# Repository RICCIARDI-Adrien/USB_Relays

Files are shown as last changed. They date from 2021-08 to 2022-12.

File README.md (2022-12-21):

# USB relays

Control separately 16 signal relays through a PC by using a standard USB connection and a simple text-based serial protocol.  
Each relay can switch up to 3A at 24VDC (warning : this board is not designed for AC current).  
There is no need for a separate power supply to power the board, it is designed to be fully powered by the USB connection (that's why small relays are used).

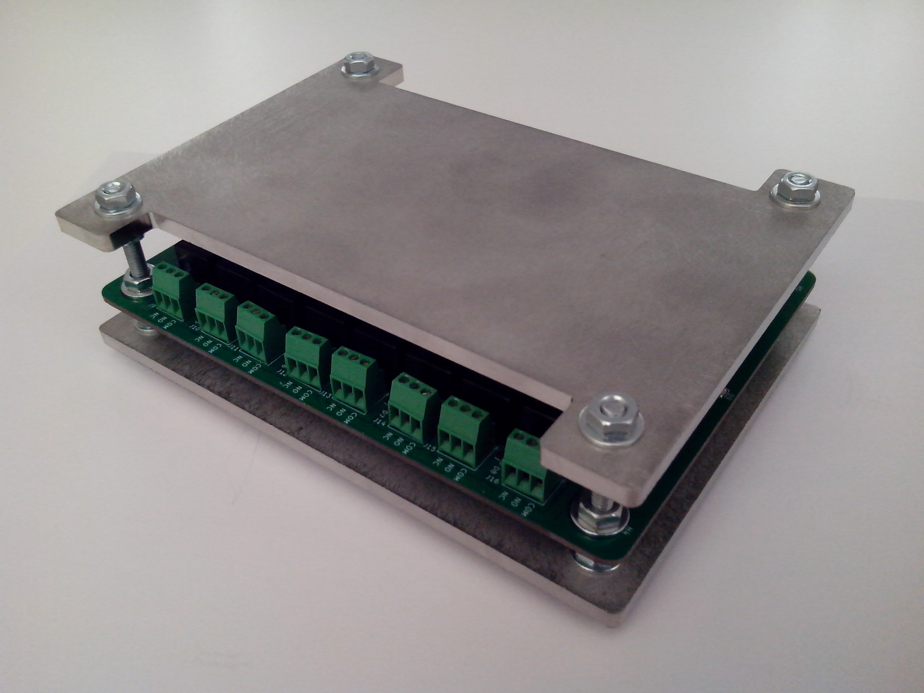
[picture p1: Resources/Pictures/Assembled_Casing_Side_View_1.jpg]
Assembled casing side view

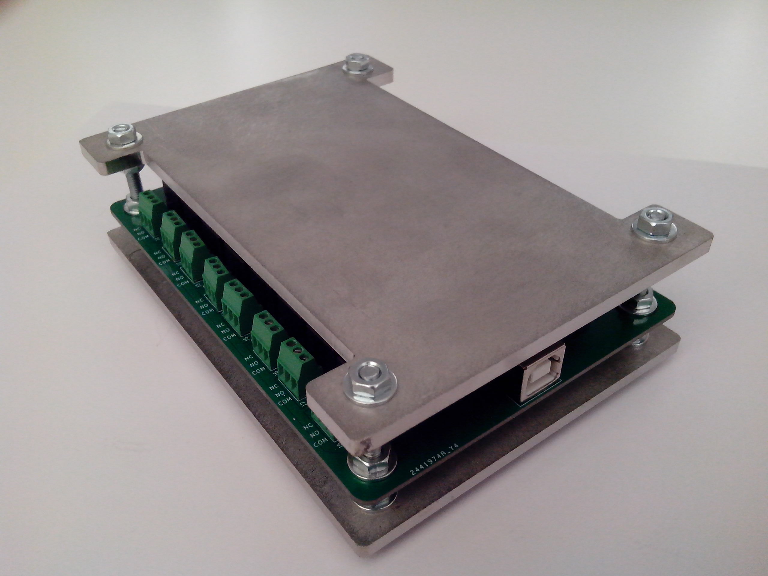
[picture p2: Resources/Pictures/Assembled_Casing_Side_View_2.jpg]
Assembled casing side view


## Communication protocol

* The board provides an USB serial port with the following settings : **115200 bits/s, no parity, 1 stop bit**.
* All commands are ASCII-only to allow to easily use the board with a simple serial port terminal like `Putty`, `minicom`, `picocom`, etc. If you plan to send commands manually, enable local echo and send CRLF when pressing enter key (see below). Here is an example picocom command invocation : `picocom --echo --omap crcrlf -b 115200 /dev/ttyUSB0`.
* All commands start with the character `#`. This way, if you mess up and write the commands into an UNIX terminal, they will be interpreted as comments.
* All commands end with CRLF characters (`\r\n`), so you only have to press `enter` key to send the command to the board.
* All commands sent to the board return an answer, the board will ignore all other commands while it is processing the current one. This allows to throttle a fast PC sending too much commands at a time, it must wait for each command answer before sending the next one.
* If you don't know the board state (for instance, the PC rebooted while it was sending a command and the board has received an incomplete command and is stuck waiting for the remaining part of the command), send the `!` character at any time. The board will immediately clear its reception buffer.

## Commands list

Use the `#H<CR><LF>` command to display the following list of commands :
```
Commands :
  - Get a relay state : #Gxx
    'xx' is the relay ID, from 1 to 16.
  - Display this help : #H
  - Set led state : #Lv
    'v' is the led state value (0 to turn off, 1 to turn on, 2 to make it blink).
  - Set relay state : #Sxxv
    'xx' is the relay ID, from 1 to 16.
    'v' is the relay state value (0 to clear, 1 to set).
  - Get firmware version : #V
```

## Photo gallery

### Casing plates

Plates are made of 4mm-thick 304 stainless steel.
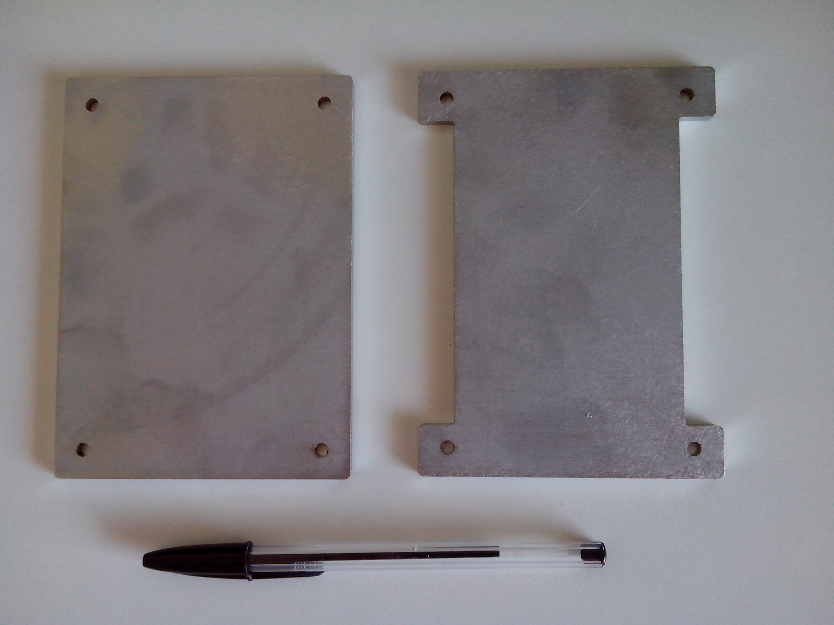
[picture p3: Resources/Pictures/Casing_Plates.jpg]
Casing plates


### PCB

PCB top :
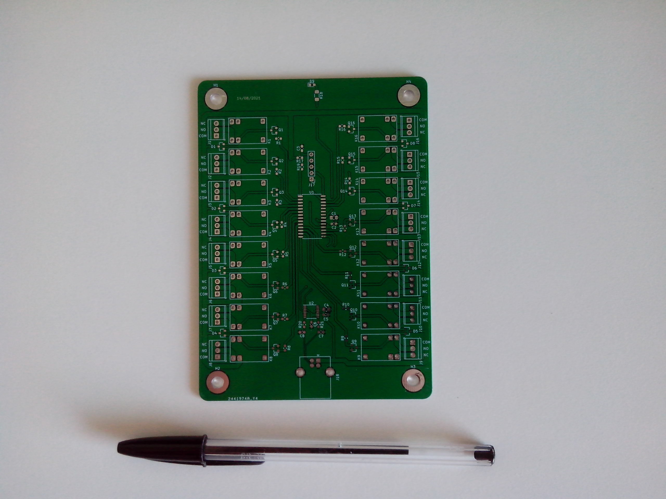
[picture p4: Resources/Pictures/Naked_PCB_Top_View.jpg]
PCB top view


PCB bottom :
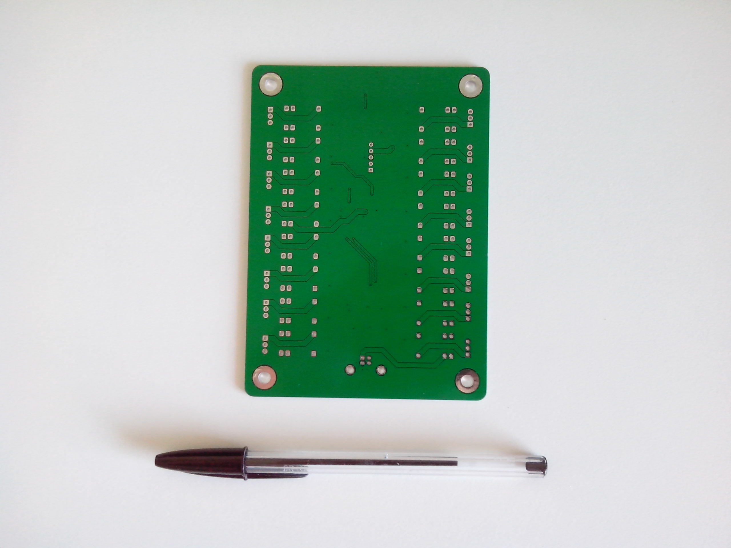
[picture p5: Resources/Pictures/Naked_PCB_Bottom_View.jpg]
PCB bottom view


### Assembled PCB

Assembled PCB top :
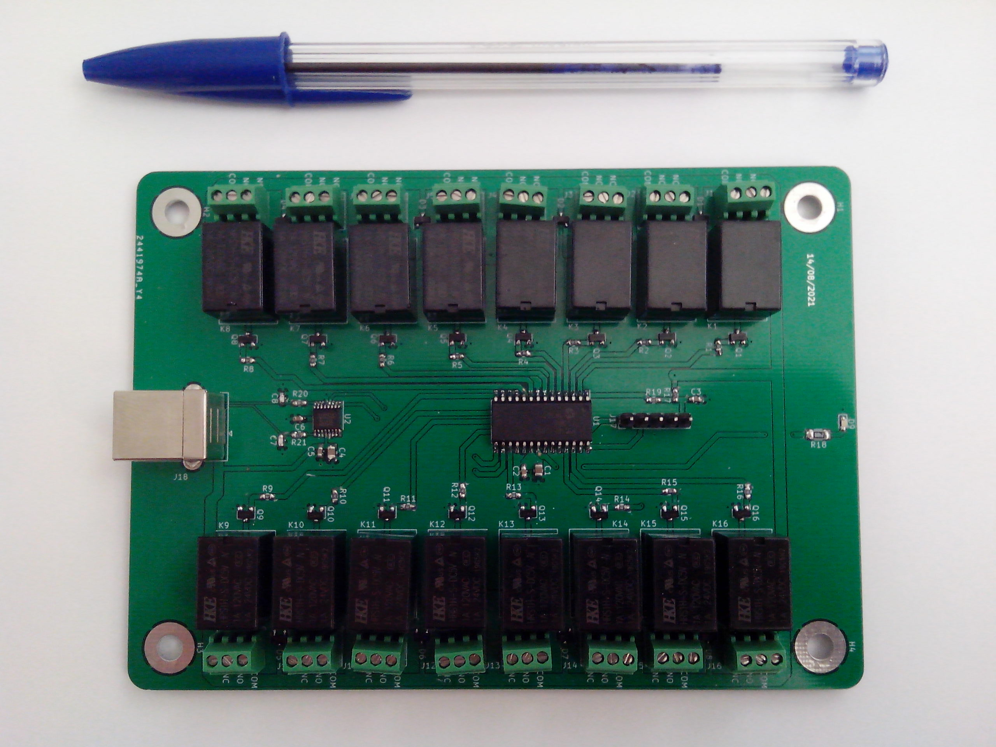
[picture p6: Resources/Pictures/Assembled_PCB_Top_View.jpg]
Assembled PCB top view


Assembled PCB bottom :
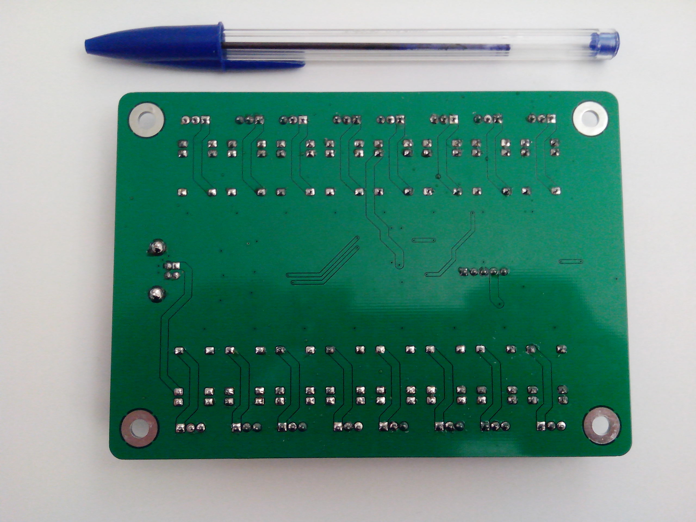
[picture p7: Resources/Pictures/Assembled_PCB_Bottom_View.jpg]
Assembled PCB bottom view


### Casing assembly

Screwing the bolts on the casing lower steel plate :
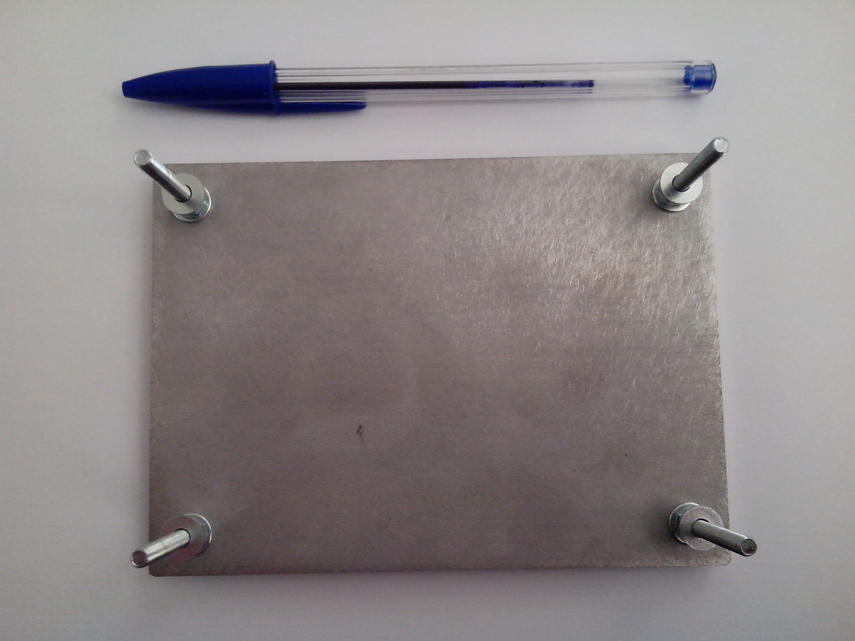
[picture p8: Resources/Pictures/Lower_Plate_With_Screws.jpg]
Lower plate with screws


Fixing the PCB :
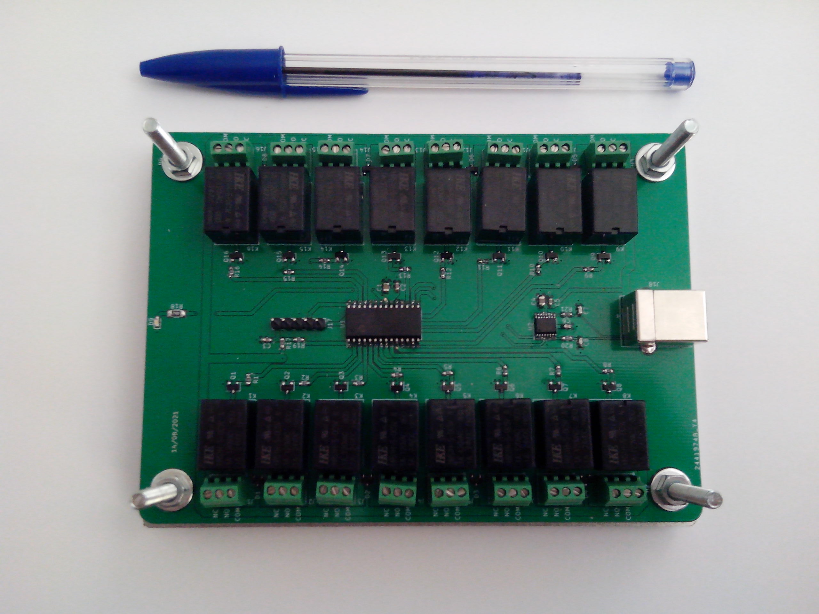
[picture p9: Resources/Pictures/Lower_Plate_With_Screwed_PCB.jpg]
Lower plate with screwed PCB


Fixing the casing upper steel plate :
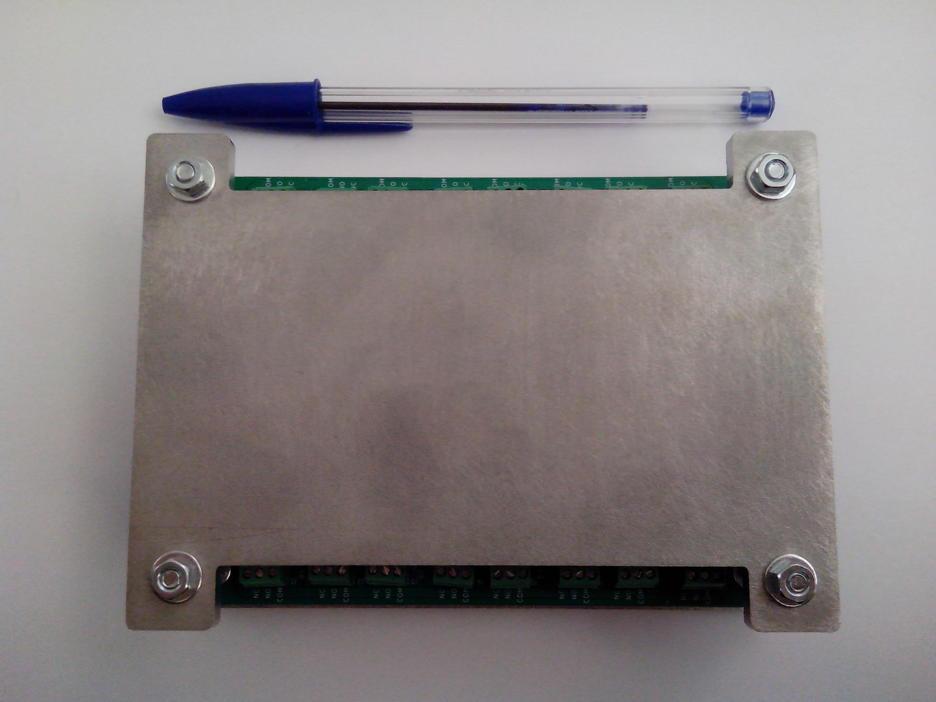
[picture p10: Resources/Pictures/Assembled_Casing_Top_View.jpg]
Assembled casing top view


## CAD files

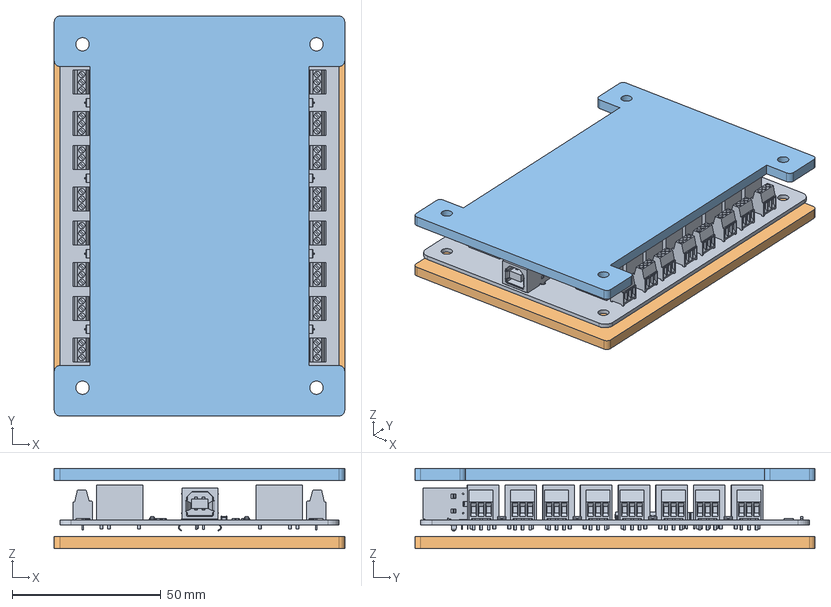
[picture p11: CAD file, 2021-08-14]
Casing/Casing.FCStd
97.8 x 134.6 x 27.0 mm
PCB
Bottom_Plate
Top_Plate

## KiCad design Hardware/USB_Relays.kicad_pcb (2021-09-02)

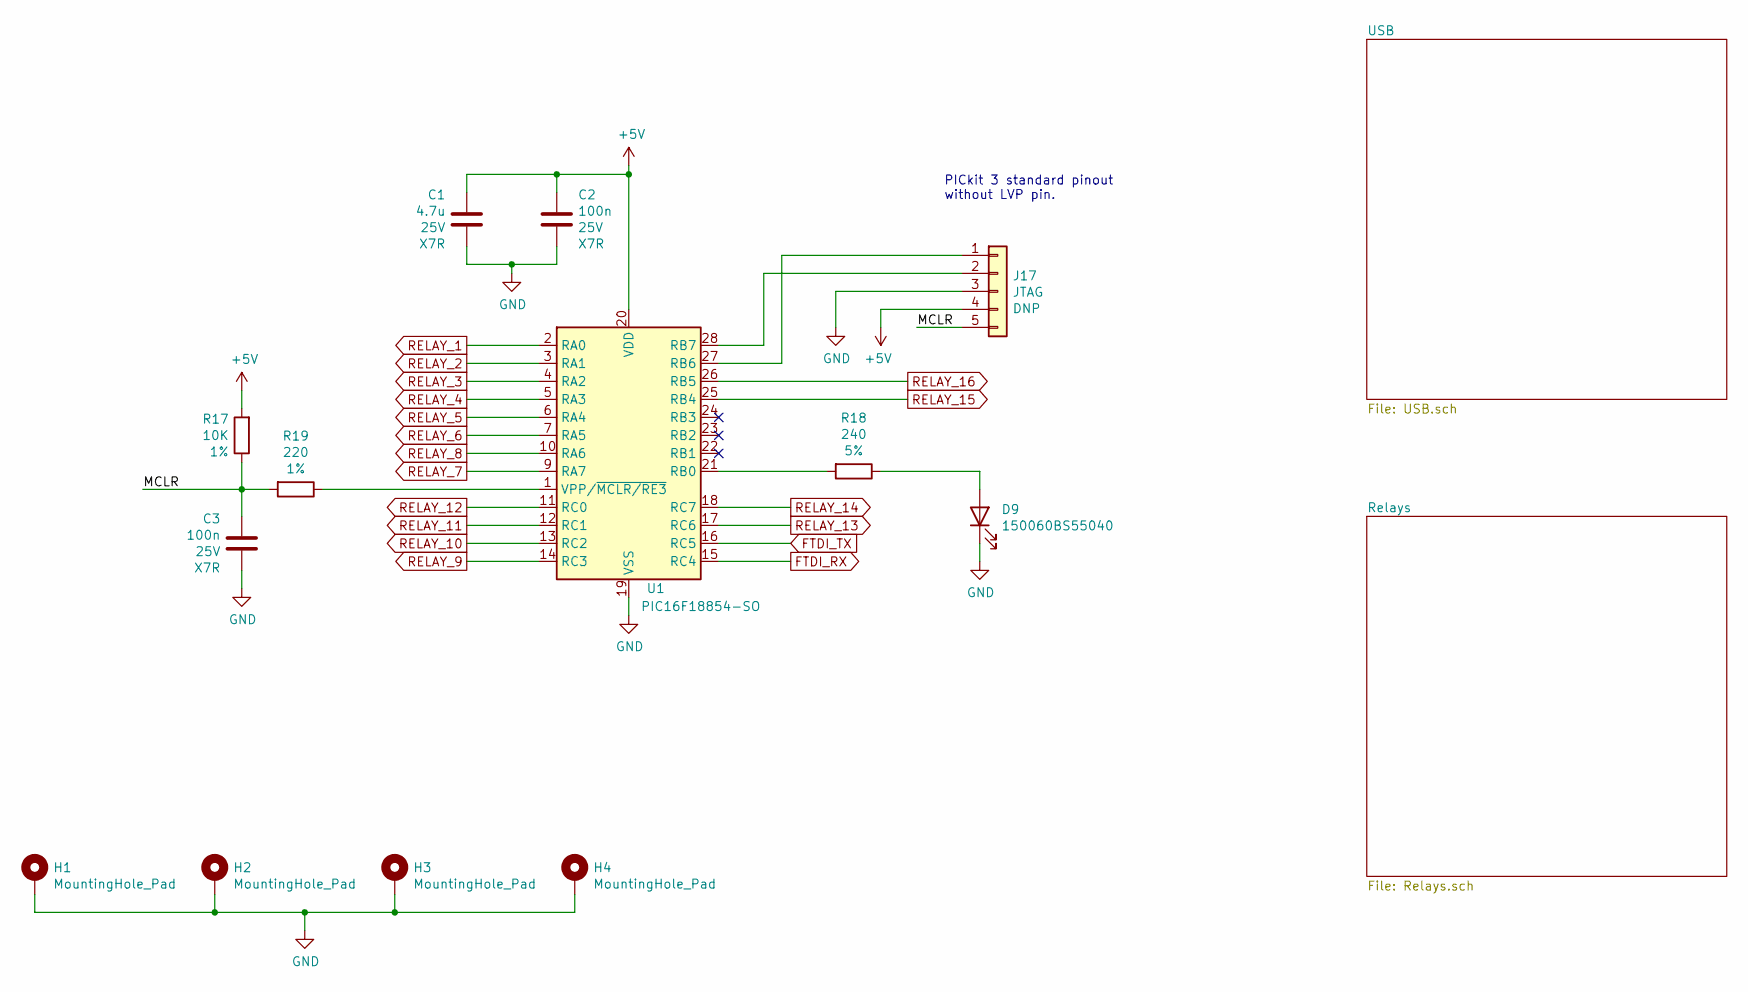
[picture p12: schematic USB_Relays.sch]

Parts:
C1: 4.7u; C_0805_2012Metric_Pad1.18x1.45mm_HandSolder
C2, C3: 100n; C_0603_1608Metric_Pad1.08x0.95mm_HandSolder
D9: 150060BS55040; LED_0603_1608Metric_Pad1.05x0.95mm_HandSolder
H1, H2, H3, H4: MountingHole_Pad; MountingHole_4.5mm_Pad
J17: JTAG; PinHeader_1x05_P2.54mm_Vertical
R17: 10K; R_0603_1608Metric_Pad0.98x0.95mm_HandSolder
R18: 240; R_1206_3216Metric_Pad1.30x1.75mm_HandSolder
R19: 220; R_0603_1608Metric_Pad0.98x0.95mm_HandSolder
U1: PIC16F18854-SO; SOIC-28W_7.5x17.9mm_P1.27mm

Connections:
+5V: C1.1, C2.1, J17.4, R17.2, U1.20 (VDD); also elsewhere on the board
/MCLR: C3.1, J17.5, R17.1, R19.2
FTDI_RX: U1.15 (RC4); also elsewhere on the board
FTDI_TX: U1.16 (RC5); also elsewhere on the board
GND: C1.2, C2.2, C3.2, D9.1 (K), H1.1, H2.1, H3.1, H4.1, J17.3, U1.8 (VSS), U1.19 (VSS); also elsewhere on the board
unnamed: D9.2 (A), R18.1
unnamed: J17.1, U1.27 (RB6)
unnamed: J17.2, U1.28 (RB7)
unnamed: R18.2, U1.21 (RB0)
unnamed: R19.1, U1.1 (VPP/~MCLR/RE3)
RELAY_1: U1.2 (RA0); also elsewhere on the board
RELAY_2: U1.3 (RA1); also elsewhere on the board
RELAY_3: U1.4 (RA2); also elsewhere on the board
RELAY_4: U1.5 (RA3); also elsewhere on the board
RELAY_5: U1.6 (RA4); also elsewhere on the board
RELAY_6: U1.7 (RA5); also elsewhere on the board
RELAY_7: U1.9 (RA7); also elsewhere on the board
RELAY_8: U1.10 (RA6); also elsewhere on the board
RELAY_9: U1.14 (RC3); also elsewhere on the board
RELAY_10: U1.13 (RC2); also elsewhere on the board
RELAY_11: U1.12 (RC1); also elsewhere on the board
RELAY_12: U1.11 (RC0); also elsewhere on the board
RELAY_13: U1.17 (RC6); also elsewhere on the board
RELAY_14: U1.18 (RC7); also elsewhere on the board
RELAY_15: U1.25 (RB4); also elsewhere on the board
RELAY_16: U1.26 (RB5); also elsewhere on the board

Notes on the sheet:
PICkit 3 standard pinout without LVP pin.

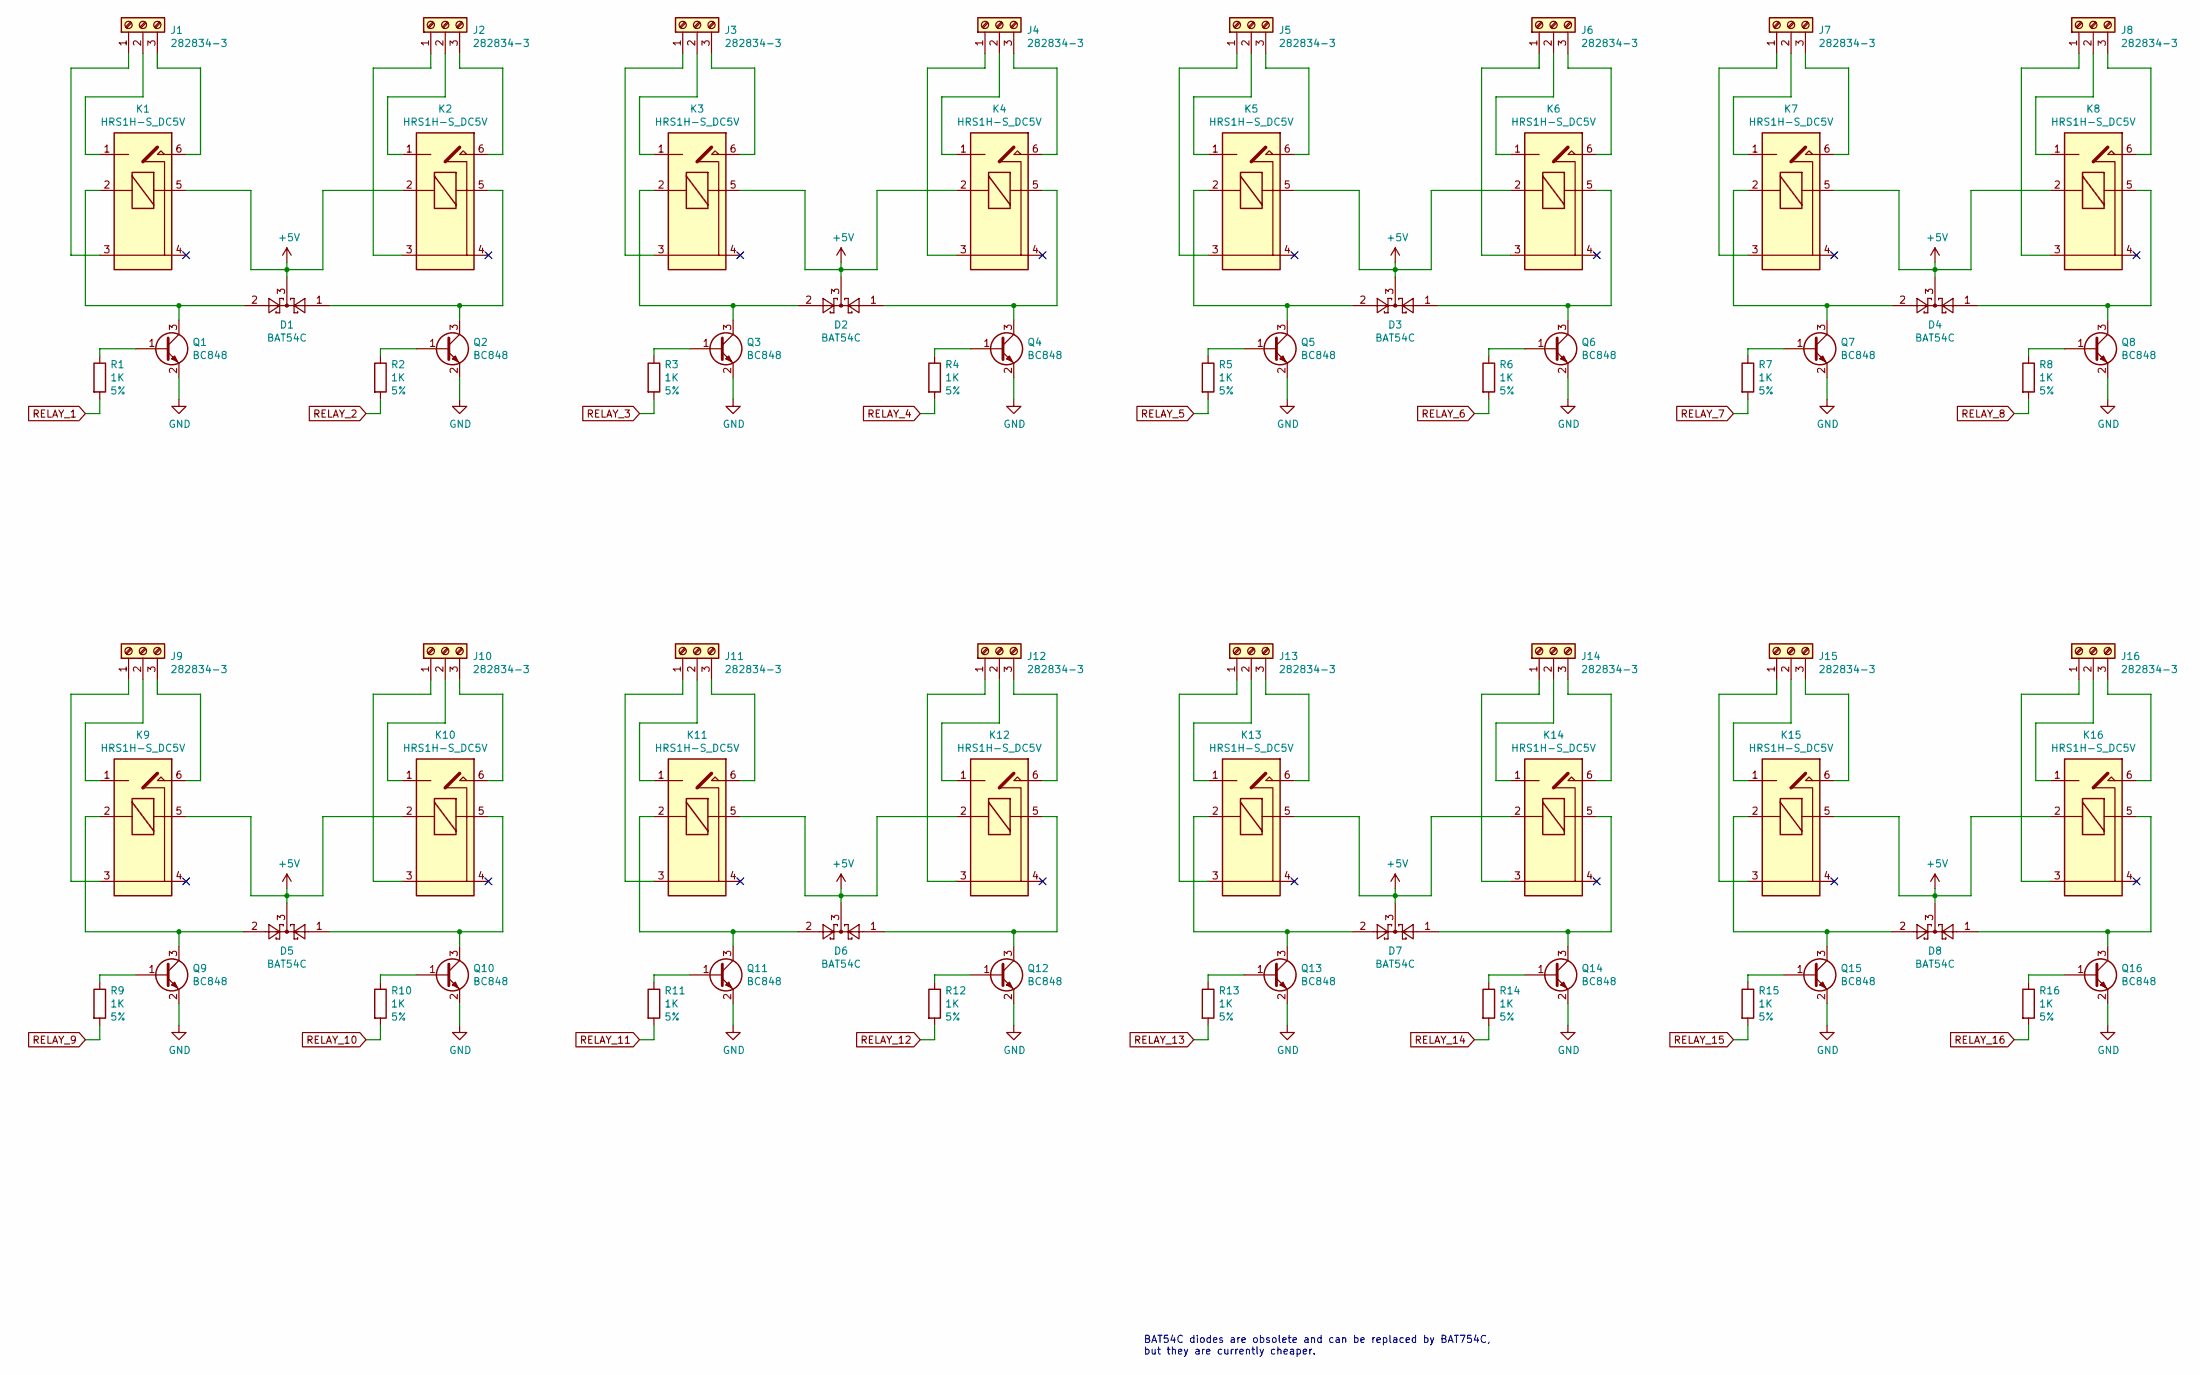
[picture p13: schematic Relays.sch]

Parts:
D1, D2, D3, D4, D5, D6, D7, D8: BAT54C; SOT-23
J1, J2, J3, J4, J5, J6, J7, J8, J9, J10, J11, J12, J13, J14, J15, J16: 282834-3; TerminalBlock_TE_282834-3_1x03_P2.54mm_Horizontal
K1, K2, K3, K4, K5, K6, K7, K8, K9, K10, K11, K12, K13, K14, K15, K16: HRS1H-S_DC5V; HRS1H-S
Q1, Q2, Q3, Q4, Q5, Q6, Q7, Q8, Q9, Q10, Q11, Q12, Q13, Q14, Q15, Q16: BC848; SOT-23
R1, R2, R3, R4, R5, R6, R7, R8, R9, R10, R11, R12, R13, R14, R15, R16: 1K; R_0603_1608Metric_Pad0.98x0.95mm_HandSolder

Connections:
+5V: D1.3, D2.3, D3.3, D4.3, D5.3, D6.3, D7.3, D8.3, K1.5, K2.2, K3.5, K4.2, K5.5, K6.2, K7.5, K8.2, K9.5, K10.2, K11.5, K12.2, K13.5, K14.2, K15.5, K16.2; also elsewhere on the board
GND: Q1.2 (E), Q2.2 (E), Q3.2 (E), Q4.2 (E), Q5.2 (E), Q6.2 (E), Q7.2 (E), Q8.2 (E), Q9.2 (E), Q10.2 (E), Q11.2 (E), Q12.2 (E), Q13.2 (E), Q14.2 (E), Q15.2 (E), Q16.2 (E); also elsewhere on the board
unnamed: D1.1, K2.5, Q2.3 (C)
unnamed: D1.2, K1.2, Q1.3 (C)
unnamed: D2.1, K4.5, Q4.3 (C)
unnamed: D2.2, K3.2, Q3.3 (C)
unnamed: D3.1, K6.5, Q6.3 (C)
unnamed: D3.2, K5.2, Q5.3 (C)
unnamed: D4.1, K8.5, Q8.3 (C)
unnamed: D4.2, K7.2, Q7.3 (C)
unnamed: D5.1, K10.5, Q10.3 (C)
unnamed: D5.2, K9.2, Q9.3 (C)
unnamed: D6.1, K12.5, Q12.3 (C)
unnamed: D6.2, K11.2, Q11.3 (C)
unnamed: D7.1, K14.5, Q14.3 (C)
unnamed: D7.2, K13.2, Q13.3 (C)
unnamed: D8.1, K16.5, Q16.3 (C)
unnamed: D8.2, K15.2, Q15.3 (C)
unnamed: J1.1, K1.3
unnamed: J1.2, K1.1
unnamed: J1.3, K1.6
unnamed: J2.1, K2.3
unnamed: J2.2, K2.1
unnamed: J2.3, K2.6
unnamed: J3.1, K3.3
unnamed: J3.2, K3.1
unnamed: J3.3, K3.6
unnamed: J4.1, K4.3
unnamed: J4.2, K4.1
unnamed: J4.3, K4.6
unnamed: J5.1, K5.3
unnamed: J5.2, K5.1
unnamed: J5.3, K5.6
unnamed: J6.1, K6.3
unnamed: J6.2, K6.1
unnamed: J6.3, K6.6
unnamed: J7.1, K7.3
unnamed: J7.2, K7.1
unnamed: J7.3, K7.6
unnamed: J8.1, K8.3
unnamed: J8.2, K8.1
unnamed: J8.3, K8.6
unnamed: J9.1, K9.3
unnamed: J9.2, K9.1
unnamed: J9.3, K9.6
unnamed: J10.1, K10.3
unnamed: J10.2, K10.1
unnamed: J10.3, K10.6
unnamed: J11.1, K11.3
unnamed: J11.2, K11.1
unnamed: J11.3, K11.6
unnamed: J12.1, K12.3
unnamed: J12.2, K12.1
unnamed: J12.3, K12.6
unnamed: J13.1, K13.3
unnamed: J13.2, K13.1
unnamed: J13.3, K13.6
unnamed: J14.1, K14.3
unnamed: J14.2, K14.1
unnamed: J14.3, K14.6
unnamed: J15.1, K15.3
unnamed: J15.2, K15.1
unnamed: J15.3, K15.6
unnamed: J16.1, K16.3
unnamed: J16.2, K16.1
unnamed: J16.3, K16.6
unnamed: Q1.1 (B), R1.1
unnamed: Q2.1 (B), R2.1
unnamed: Q3.1 (B), R3.1
unnamed: Q4.1 (B), R4.1
unnamed: Q5.1 (B), R5.1
unnamed: Q6.1 (B), R6.1
unnamed: Q7.1 (B), R7.1
unnamed: Q8.1 (B), R8.1
unnamed: Q9.1 (B), R9.1
unnamed: Q10.1 (B), R10.1
unnamed: Q11.1 (B), R11.1
unnamed: Q12.1 (B), R12.1
unnamed: Q13.1 (B), R13.1
unnamed: Q14.1 (B), R14.1
unnamed: Q15.1 (B), R15.1
unnamed: Q16.1 (B), R16.1
RELAY_1: R1.2; also elsewhere on the board
RELAY_2: R2.2; also elsewhere on the board
RELAY_3: R3.2; also elsewhere on the board
RELAY_4: R4.2; also elsewhere on the board
RELAY_5: R5.2; also elsewhere on the board
RELAY_6: R6.2; also elsewhere on the board
RELAY_7: R7.2; also elsewhere on the board
RELAY_8: R8.2; also elsewhere on the board
RELAY_9: R9.2; also elsewhere on the board
RELAY_10: R10.2; also elsewhere on the board
RELAY_11: R11.2; also elsewhere on the board
RELAY_12: R12.2; also elsewhere on the board
RELAY_13: R13.2; also elsewhere on the board
RELAY_14: R14.2; also elsewhere on the board
RELAY_15: R15.2; also elsewhere on the board
RELAY_16: R16.2; also elsewhere on the board

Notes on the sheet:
BAT54C diodes are obsolete and can be replaced by BAT754C, but they are currently cheaper.

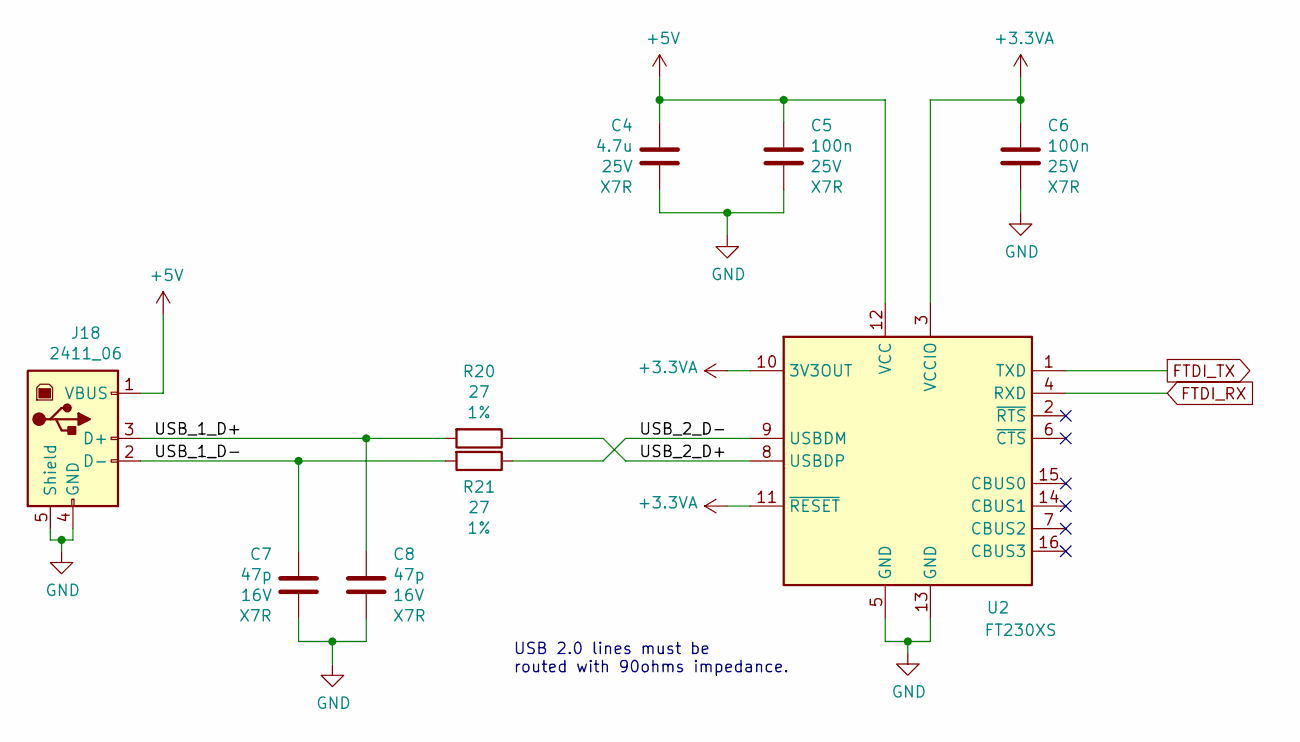
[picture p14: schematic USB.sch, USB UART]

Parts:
C4: 4.7u; C_0805_2012Metric_Pad1.18x1.45mm_HandSolder
C5, C6: 100n; C_0603_1608Metric_Pad1.08x0.95mm_HandSolder
C7, C8: 47p; C_0603_1608Metric_Pad1.08x0.95mm_HandSolder
J18: 2411_06; USB_B_OST_USB-B1HSxx_Horizontal
R20, R21: 27; R_0603_1608Metric_Pad0.98x0.95mm_HandSolder
U2: FT230XS; SSOP-16_3.9x4.9mm_P0.635mm

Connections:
+3.3VA: C6.1, U2.3 (VCCIO), U2.10 (3V3OUT), U2.11 (~RESET)
+5V: C4.1, C5.1, J18.1 (VBUS), U2.12 (VCC); also elsewhere on the board
/USB/USB_1_D+: C8.1, J18.3 (D+), R20.2
/USB/USB_1_D-: C7.1, J18.2 (D-), R21.2
/USB/USB_2_D+: R20.1, U2.8 (USBDP)
/USB/USB_2_D-: R21.1, U2.9 (USBDM)
FTDI_RX: U2.4 (RXD); also elsewhere on the board
FTDI_TX: U2.1 (TXD); also elsewhere on the board
GND: C4.2, C5.2, C6.2, C7.2, C8.2, J18.4 (GND), J18.5 (Shield), U2.5 (GND), U2.13 (GND); also elsewhere on the board

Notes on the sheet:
USB 2.0 lines must be routed with 90ohms impedance.

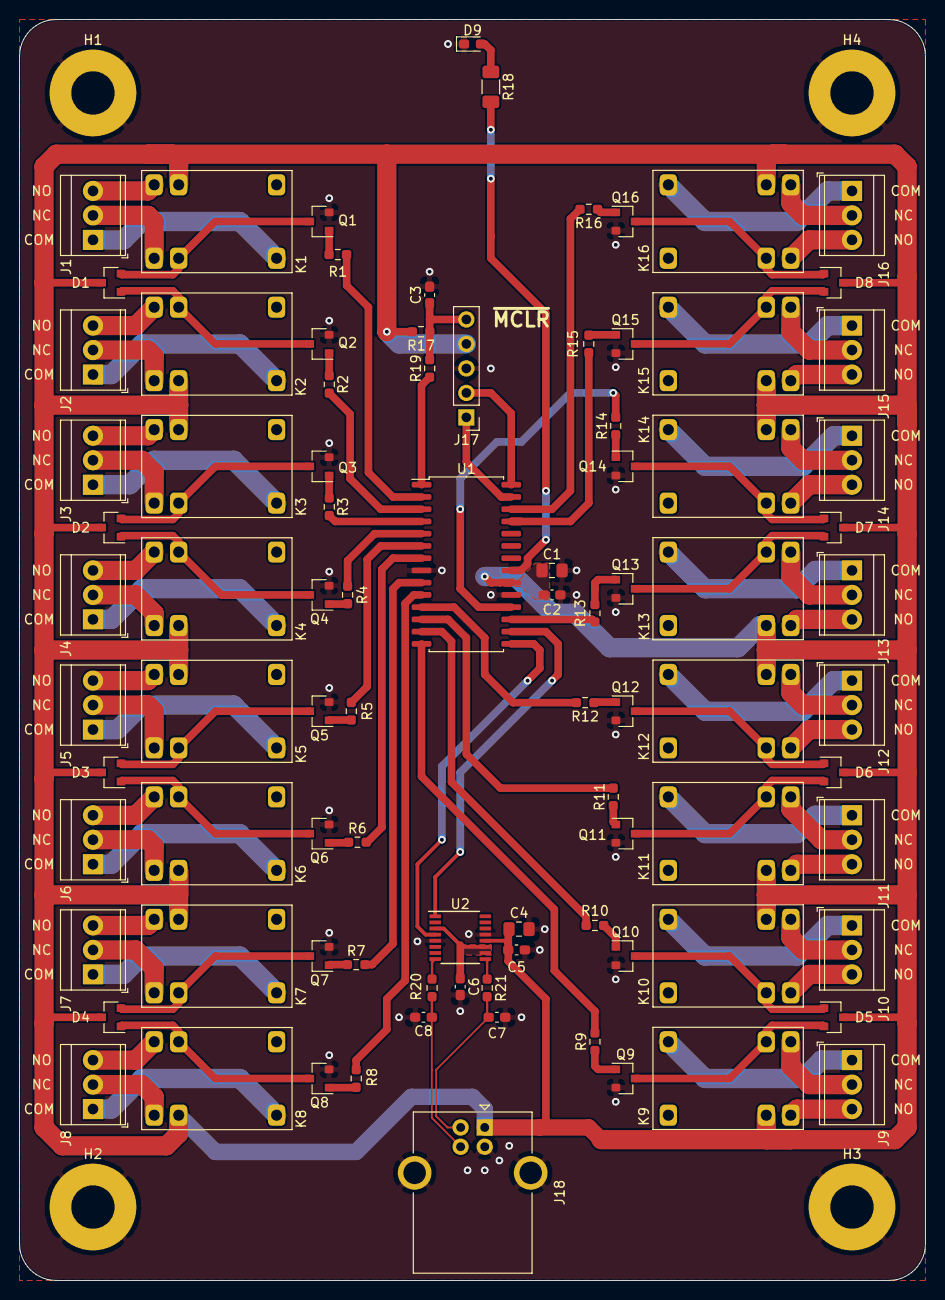
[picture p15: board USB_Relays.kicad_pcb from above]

Board: 2 copper layers, 94.0 x 130.8 mm, 94 parts (0 on the bottom side), 111 nets.

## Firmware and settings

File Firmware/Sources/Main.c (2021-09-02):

/** @file Main.c
 * Entry point and main loop.
 * @author Adrien RICCIARDI
 */
#include <Communication_Protocol.h>
#include <Led.h>
#include <Relay.h>
#include <UART.h>
#include <xc.h>

//-------------------------------------------------------------------------------------------------
// Microcontroller configuration
//-------------------------------------------------------------------------------------------------
// CONFIG1 register
#pragma config FCMEN = OFF, CSWEN = OFF, CLKOUTEN = OFF, RSTOSC = HFINT32, FEXTOSC = OFF // Disable fail-safe clock monitor, disable clock switch, disable clock out on OSC2 pin, set 32MHz internal clock (without PLL), disable external oscillator mode
// CONFIG2 register
#pragma config DEBUG = OFF, STVREN = OFF, PPS1WAY = OFF, ZCD = ON, BORV = HI, BOREN = ON, LPBOREN = OFF, PWRTE = ON, MCLRE = ON // Disable background debugger (it is automatically handled by the debug tool), disable reset on stack overflow or underflow, allow PPS register to be set multiple times, disable zero-cross detect circuit, set brown-out voltage level to high as recommended for Fosc > 16MHz, enable brown-out reset, disable low-power brown-out reset, enable power-up timer, configure MCLR pin as MCLR
// CONFIG3 register
#pragma config WDTCCS = LFINTOSC, WDTCWS = WDTCWS_0, WDTE = OFF, WDTCPS = WDTCPS_0 // Set watchdog timer reference clock to default value, set watchdog timer window to default value, disable watchdog timer, set watchdog period to default value
// CONFIG4 register
#pragma config LVP = OFF, SCANE = not_available, WRT = ON // Disable low-voltage programming, disable memory scanner module, enable program flash memory write protection
// CONFIG5 register
#pragma config CPD = OFF, CP = OFF // Disable data EEPROM code protection, disable program memory code protection

//-------------------------------------------------------------------------------------------------
// Private functions
//-------------------------------------------------------------------------------------------------
/** Called everytime an enabled interrupt fires. */
static void __interrupt MainInterruptHandler(void)
{
	if (LED_IS_INTERRUPT_PENDING()) LedInterruptHandler();
}

//-------------------------------------------------------------------------------------------------
// Entry point
//-------------------------------------------------------------------------------------------------
void main(void)
{
	unsigned char Is_Led_Lighted = 0;

	// Initialize modules
	RelayInitialize();
	UARTInitialize();
	LedInitialize();

	// Enable interrupts
	INTCONbits.PEIE = 1;
	INTCONbits.GIE = 1;

	// Turn led on to tell user that everything is up and running
	LedSetState(LED_STATE_ON);

	// Process each received command, this function does not return
	CommunicationProtocolProcessCommands();

	// Do not execute random code in case something went wrong, instead make the led blinks with an unusual frequency to tell user
	while (1)
	{
		LedSetState(Is_Led_Lighted);
		Is_Led_Lighted = !Is_Led_Lighted;
		__delay_ms(150);
	}
}

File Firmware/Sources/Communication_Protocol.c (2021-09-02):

/** @file Communication_Protocol.c
 * See Communication_Protocol.h for description.
 * @author Adrien RICCIARDI
 */
#include <Communication_Protocol.h>
#include <Configuration.h>
#include <ctype.h>
#include <Led.h>
#include <Relay.h>
#include <stdlib.h>
#include <string.h>
#include <UART.h>

//-------------------------------------------------------------------------------------------------
// Private constants
//-------------------------------------------------------------------------------------------------
/** The magic number prefixing all commands. */
#define COMMUNICATION_PROTOCOL_MAGIC_NUMBER '#'

/** This character allows to immediately clear the reception buffer. */
#define COMMUNICATION_PROTOCOL_ABORT_CHARACTER '!'

//-------------------------------------------------------------------------------------------------
// Private types
//-------------------------------------------------------------------------------------------------
/** All command reception and execution state machine states. */
typedef enum
{
	COMMUNICATION_PROTOCOL_STATE_RECEIVE_MAGIC_NUMBER,
	COMMUNICATION_PROTOCOL_STATE_RECEIVE_COMMAND_CODE,
	COMMUNICATION_PROTOCOL_STATE_RECEIVE_PAYLOAD,
	COMMUNICATION_PROTOCOL_STATE_RECEIVE_CARRIAGE_RETURN,
	COMMUNICATION_PROTOCOL_STATE_RECEIVE_LINE_FEED
} TCommunicationProtocolState;

//-------------------------------------------------------------------------------------------------
// Private variables
//-------------------------------------------------------------------------------------------------
/** Each command code is a single uppercase letter. This lookup table tells the payload size for all available commands. */
static unsigned char Command_Payload_Sizes[] =
{
	// 'A'
	0,
	// 'B'
	0,
	// 'C'
	0,
	// 'D'
	0,
	// 'E'
	0,
	// 'F'
	0,
	// 'G'
	2,
	// 'H'
	0,
	// 'I'
	0,
	// 'J'
	0,
	// 'K'
	0,
	// 'L'
	1,
	// 'M'
	0,
	// 'N'
	0,
	// 'O'
	0,
	// 'P'
	0,
	// 'Q'
	0,
	// 'R'
	0,
	// 'S'
	3,
	// 'T'
	0,
	// 'U'
	0,
	// 'V'
	0,
	// 'W'
	0,
	// 'X'
	0,
	// 'Y'
	0,
	// 'Z'
	0
};

//-------------------------------------------------------------------------------------------------
// Private functions
//-------------------------------------------------------------------------------------------------
/** Check command payload, execute the command then send the answer.
 * @param Command_Code The command to execute.
 * @param Pointer_String_Payload This string contains data only for commands that need a payload. The string is guaranteed to be zero-terminated.
 */ 
static void CommunicationProtocolExecuteCommand(unsigned char Command_Code, unsigned char *Pointer_String_Payload)
{
	unsigned char String_Answer[8], Relay_ID, Temporary_Byte;

	switch (Command_Code)
	{
		// Get relay state
		case 'G':
			// Retrieve relay ID from payload
			// Make sure digits are provided
			if (!isdigit(Pointer_String_Payload[0]) || !isdigit(Pointer_String_Payload[1]))
			{
				strcpy(String_Answer, "KO");
				break;
			}
			Relay_ID = atoi(Pointer_String_Payload);
			// Make sure relay ID is in the allowed range (from 1 to RELAYS_COUNT)
			if ((Relay_ID < 1) || (Relay_ID > RELAYS_COUNT))
			{
				strcpy(String_Answer, "KO");
				break;
			}
			// Payload is valid, execute the command
			String_Answer[0] = RelayGetState(Relay_ID - 1) + '0'; // Relay IDs are zero-based, convert the return value to an ASCII digit
			String_Answer[1] = 0; // Terminate the string
			break;

		// Display help
		case 'H':
			UARTWriteString("--- USB relays by Adrien RICCIARDI ---\r\n"
				"Commands :\r\n"
				"  - Get a relay state : #Gxx\r\n"
				"    'xx' is the relay ID, from 1 to 16.\r\n"
				"  - Display this help : #H\r\n"
				"  - Set led state : #Lv\r\n"
				"    'v' is the led state value (0 to turn off, 1 to turn on, 2 to make it blink).\r\n"
				"  - Set relay state : #Sxxv\r\n"
				"    'xx' is the relay ID, from 1 to 16.\r\n"
				"    'v' is the relay state value (0 to clear, 1 to set).\r\n"
				"  - Get firmware version : #V\r\n"
				"Useful information :\r\n"
				"  - Write the '!' character at any time to discard everything that was written before.\r\n"
			    "  - A command that do not return a specific result will return 'OK' on success or 'KO' if a parameter is bad.\r\n");
			// The answer has been displayed, no need to display more text
			return;

		// Set led state
		case 'L':
			// Retrieve state from payload
			Temporary_Byte = Pointer_String_Payload[0];
			if ((Temporary_Byte < '0') || (Temporary_Byte > '2'))
			{
				strcpy(String_Answer, "KO");
				break;
			}
			// Payload is valid, execute the command
			Temporary_Byte -= '0'; // Convert to binary
			LedSetState(Temporary_Byte);
			strcpy(String_Answer, "OK");
			break;

		// Set relay state
		case 'S':
			// Make sure only digits are provided for the relay ID
			if (!isdigit(Pointer_String_Payload[0]) || !isdigit(Pointer_String_Payload[1]))
			{
				strcpy(String_Answer, "KO");
				break;
			}
			// Make sure the relay state value is in the allowed range
			Temporary_Byte = Pointer_String_Payload[2];
			if ((Temporary_Byte < '0') || (Temporary_Byte > '1'))
			{
				strcpy(String_Answer, "KO");
				break;
			}
			Temporary_Byte -= '0'; // Convert to binary value
			// Retrieve relay ID from payload
			Pointer_String_Payload[2] = 0; // Terminate the string just after the relay ID digits, so atoi() can be directly called, this will work because relay state value is saved to Temporary_Byte variable 
			Relay_ID = atoi(Pointer_String_Payload);
			// Make sure relay ID is in the allowed range (from 1 to RELAYS_COUNT)
			if ((Relay_ID < 1) || (Relay_ID > RELAYS_COUNT))
			{
				strcpy(String_Answer, "KO");
				break;
			}
			// Payload is valid, execute the command
			RelaySetState(Relay_ID - 1, Temporary_Byte); // Relay IDs are zero-based
			strcpy(String_Answer, "OK");
			break;

		// Get firmware version
		case 'V':
			strcpy(String_Answer, CONFIGURATION_FIRMWARE_VERSION_STRING);
			break;

		// Unknown command
		default:
			strcpy(String_Answer, "KO");
			break;
	}

	// Send the answer
	strcat(String_Answer, "\r\n"); // Always add the answer suffix
	UARTWriteString(String_Answer);
}
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

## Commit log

2021-08-12 [Hardware] Started schematic. Added USB UART sheet.
    [Relays.sch, USB.sch, USB_Relays.kicad_pcb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]
2021-08-12 [Hardware] Added USB-B connector reference and 3D model.
    [USB.sch, USB_Relays.kicad_pcb]
2021-08-12 [Hardware] Added HRS1H-S DC5V relay symbol, footprint and 3D model.
    [USB_Relays.kicad_pcb]
2021-08-12 [Hardware] Added relays schematic sheet.
    [Relays.sch, USB.sch, USB_Relays.kicad_pcb]
2021-08-12 [Hardware] Added terminal 3D models.
    [Relays.sch, USB_Relays.kicad_pcb, USB_Relays.sch]
2021-08-13 [Hardware] Added microcontroller-related schematic.
    [USB_Relays.sch]
2021-08-13 [Hardware] Positioned components on PCB.
    [USB.sch, USB_Relays.kicad_pcb, USB_Relays.sch]
2021-08-13 [Hardware] Renamed components in a more coherent way.
    [Relays.sch, USB.sch, USB_Relays.kicad_pcb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]
2021-08-14 [Hardware] Ignored KiCad automatically generated cache file.
2021-08-14 [Hardware] Added mounting holes, PCB contour and ground planes.
    [USB_Relays.kicad_pcb, USB_Relays.sch]
2021-08-14 [Hardware] Routed whole PCB.
    [USB_Relays.kicad_pcb, USB_Relays.sch]
2021-08-14 [Hardware] Moved LED to make it more visible, cleaned components designation positions, added information about connectors pins to the PCB.
    [USB_Relays.kicad_pcb]
2021-08-14 [Hardware] Made round PCB corners.
    [USB_Relays.kicad_pcb]
2021-08-14 [Casing] Added first casing version with top and bottom plates, plus top plate holes to get access to terminal blocks.
    [Casing.FCStd]
2021-08-14 [Hardware] Improved bill of materials generation.
    [USB_Relays.kicad_pcb, USB_Relays.sch]
2021-08-30 [Firmware] Added empty project with blinking led test.
2021-08-31 [Firmware] Added relay module and a simple test.
2021-08-31 [Firmware] Added UART module and a simple test.
2021-08-31 [Firmware] Moved led management code to a dedicated module.
2021-09-01 [Firmware] Started communication protocol implementation. Added the 'get version' command.
    [Configuration.h]
2021-09-01 [Firmware] Added 'set relay state' communication protocol command.
2021-09-01 [Firmware] Added 'get relay state' communication protocol command.
2021-09-01 [Firmware] Added 'clear relay state' communication protocol command.
2021-09-01 [Firmware] Added 'set led state' communication protocol command.
2021-09-02 [Firmware] Removed 'clear relay state' communication protocol command and allowed to set or clear a relay from the 'set relay state' command. This is the same philosophy than the 'set led' command.
2021-09-02 [Firmware] Allowed to make the led blink through the 'set led state' communication protocol command. This is useful to find a specific board in the middle of a lab.
2021-09-02 [Hardware] Inverted relays 'NC' and 'NO' markings on PC silkscreen to match real relay internal connections.
    [USB_Relays.kicad_pcb]
2021-09-02 [Software] Added a simple Linux shell script testing some of the board features.
2021-09-04 [Software] Added more tests to the board testing script.
2021-09-04 [Resources] Added casing plates and PCB pictures to README.md photo gallery.
2022-12-20 [Firmware] Increased UART baud rate from 9600 bit/s to 115200 bit/s.
2022-12-20 [Firmware] Bumped version to 1.1.
    [Configuration.h]
2022-12-20 [Software] Increased the board testing script serial port speed to 115200 bit/s.
